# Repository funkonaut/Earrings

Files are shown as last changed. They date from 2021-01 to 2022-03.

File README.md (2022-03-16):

# Earrings
Light up earring art.

[Check out the project website here](https://funkonaut.github.io/project_doc/)

# Design Files
.brd and .sch files availble for EAGLE CAD. 

For each design folder there is also:
- Images of the physical boards
- .step 3D models
- Rendered images of the top and bottom of the board
- A BOM (bill of materials) for the design

# Doc
You can find a prefab checklist and some notes on design rules/process in the .csv and .pdfs. 

There is also a project write up that goes into detail on the design, assembly, and marketing/sales processes that went into this project.

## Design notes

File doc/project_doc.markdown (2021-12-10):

--- 
layout: page
title: "Project Documentation" 
description:
image: /assets/images/doc/Alien_main.jpg
author: Chris Correll
tags: 
--- 

# Emoji Earring Project 

This is the documentation website for a project I undertook in February through April of 2020. I am just now getting around to documenting everything (its December 2021) because I need to wrap up the project so I can feel good about moving on to other designs. What follows is a as comprehensive as I could manage effort to document the whole process from design to manufacturing to marketing. I made a lot of mistake, learned a lot, and over all enjoyed the process immensely (or atleast most parts of the process 😉). Enjoy! 

## Project Background
The project all began when I got my ears pierced...
Chris with pierced ears
I am a hardware nerd at heart and love all things that go blink so I figured a great project would be designing some cool interactive earings. After researching what existed out there and finding that almost everything was either lame or not my style (the folks at [CaliforniaSteam on Tindie](https://www.tindie.com/stores/californiasteam/) are doing cool things but not quite what I wanted) Lame earring I figured it was best to DIY. Additionally, I wanted to know what it would be like to take multiple designs from idea to product line, as well as a personal challenge, see if I could make something that people would actually want to buy. Thusly emoji earrings was born 👂👶.

## Initial Designs

I can't remember how I first came up with the idea to use emojis specifically I think it had something to do with my limited design skills and coming across a trove of open source SVG files for emojis. Perhaps I could just say it came to me out of the ether and leave it at that. After ideating on several different ideas from simple geometric shapes to more complex fractal esque designs I decided to go with a less is more approach and pick something that was universally loved and that I could easily acquire design files for [open source emojis!](https://github.com/hfg-gmuend/openmoji).

After I had figured out the concept for my product line I began thinking about the circuit design. Originally I wanted to do something very circuit heavy with a SAMD microcontroller, a rechargable LiPo battery, and individually addressable LEDs, but I had to remind myself of my limited soldering set up (hot air gun and manual tweezers, see Assembly & Manufacturing section below) and that the focus on the project was creating and manufacturing a product to sell not winning a hacakday hardware design competition... Earring schematic I also decided that I wanted to do one of my favorite emojis the smiley devil so that maybe later on I could also do an angel as well (which I did)!

With a schematic designed I started thinking about parts and board dimensions. I knew I wanted the earrings to be light and small as well I wanted them to be cheap to make, so I scoured digikey and mouser for parts and eventually came up with a high level bill of materials (BOM) that I could base my designs around. I went ahead and ordered some of the parts for prototyping. Devil high level BOM 

With a schematic and a first pass at a BOM it was time to start designing in Eagle. The first challenge was getting the board outline and art into Eagle. Eagle is not made for PCB art but a few smart people have figured out how to finagle it into getting great results. I ended finding [this video by Hackster.io](https://www.youtube.com/watch?v=Wu3JGQQvobg) that made the process super straightforward (well maybe just kind of straight forward). I got my art design from svg to illustrator and then split it up into layers for the pcb art. For a more in depth discussion of what I had to do check out the video above. I also made sure to print my designs on paper to make sure I got a good size for the board.
This is a design I have I split things up into layers and export them all individually
*This is a design I have in illustrator its not the devil design but one I did not end up manufacturing. I split each layer up so I can export and import them into the correct board layer in EAGLE. Its all covered in the wonderful tutorial video linked above (seriously watch that whole video its great).*

Once I got a good size in illustrator I brought my PCB art layers into Eagle starting with the dimension first. Pretty early on I nixed the cr2032 battery design as it was too big for my liking. So I had one BOM item with different foot prints crossed out but was still un decided on a switch, so I ended up designing two different boards. I spent a lot of time thinking about layout for these boards. I would constantly print and then layout my components on printouts of the front and back of the board this really helped make sure I would be able to assemble a bunch of these by hand and that I could minimize the size of the boards and maintain enough clearance for someone to change out the battery. 

Devil final board design
*Dimensions are in millimeters*

## First Prototypes
First Prototype
*First prototype noticed that the face plate is a little smaller than the board outline. Also this was not yet glued hence out of alignment.*

I got the details as perfect as I could manage and I put in two orders to OSH park for some boards. While I was waiting for the OSH park orders a friend of mine who had access to a cnc mill offered to mill out one of my designs for beer (thanks Zoltan!) so I ended up getting the chunkier switch design in before the boards. I soldered it up and it all worked! I then proceeded to test different resistor values and leds to find the best brightness for lowest current consumption (V=IR thanks math!). I ended settling on 2.2k, also had a lot of those around in 0603 packages. When I had the boards soldered up I had the idea of adding an acrylic faceplate to it to add some heft and more interest to the design as it was still very light. Since I already had the vector file of the outline from desiging the outline cutting it out on a friends laser cutter was pretty straight forward. Unfortunately I didn't realize that the milled circuit board dimensions were slightly larger than the design file so the first pass had the board peaking out from underneath. I went ahead and dialted the vector file slightly just in case as I was fine with a little bit of acrylic face plate over hang but not with any board showing underneath the acrylic outline.
Clear frosted acrylic faceplate
Originally I was gonna go with a clear frosted acrylic as I thought it might diffuse some of the light interestingly but I did not really do much as the angle that the light was being emitted was not all that wide so it just shot throug the eye holes in the acrylic. So I decided on going with a pink sheet of acrylic. 

Alien board design
*Dimensions are in millimeters*

While I was waiting on boards to come in I also started designing my second piece an alien emoji. This design went a little quicker since I had gotten the PCB art Eagle design process down better. Once I was happy with the design I went ahead and ordered some boards from PCB Way. I love OSH park but I had to do the alien in green also I wanted to see what a thinner board felt like. With two different designs under way I decided to get organized a created some project organization bags.

Project Organization bags post project so they are full
*Project Organization bags post project so they are full*

Also being PCB Way where 5 boards and 50 boards have a cost differential of about $20 I went ahead and bought a bunch (like 60), a mistake I would later come to regret... 

Tiny switch
*So smol*

Around 2 weeks later I got the devil boards back from OSH park. I soldered up both a chunky switch and a small switch design they both worked great, but the small switch was very cumbersome to turn off and on so I ditched it. I had my BOM finalized so I but in an order to OSH park for 48 boards and then bought all my parts plus around 5% extra from digikey. While the boards from PCB Way's cost scaled well, parts and OSH park boards did not so I ended up spending a bunch of money, but no big deal I would recoup that cost by selling them, little did I know...

Laser cut green faceplate
Once I got the aliens back I started experimenting with laser cut face plates for them and found that I liked a transulent green finish instead of a solid green finish. I liked being able to see the pcb board underneath. This would lead to some minor issues later during assembly and manufacturing. 

## Assembly & Manufacturing

Ready to Assemble

Now that I had all the boards it was time to start manufacturing and assembly. This is the part of the process that I really started to loathe. Assembling over 100 circuit boards with a hot air gun and soldering iron is hell, I really feel for those factory workers. My set up could have definietly been better and eventually I did get a small reflow over from a friend (thanks again Zolatan!) and cut out some solder stencil out of kapton, but I defintely learned that while assemblying prototypes is fun, assemblying for manufacturing is work. I ended up making it through about 1/2 of the boards before throwing in the towel.
So many boards
 
All in all it was sometimes nice to get in a flow for a couple of hours and knock out 8 or 9 boards but I know now why a pick and place machine exits. I didn't have a nice microscope to aide in hand placement and I definitely got eye strain over a stretch of time. I think in the future getting a set up similar to [this guy](https://www.youtube.com/watch?v=HmPYuOIMDJs) would be useful. I still have around 50 or so unassembled baords and maybe one day I will get to making them but I am happy with having made as many earring pairs as I did.

Laser cut sheet of alien faceplates
In addition to the PCB assembly process I also had to figure out an assembly process for the acrylic face plates. Laser cutting the acrylic ended up being a little trickier then I thought. I wasn't working with the best machine out their and it did take a couple of passes to get through the acrylic. As well the laser strength would sometimes leave marks on the acrylic. For the solid pink devil face plates this was not as much as of an issue. I could just flip them over and use the unmarred side but I had to trash some of the alien face plates good thing I ended up cutting like 30 extra since I had the acrylic and it was relatively unexpensive.

Laser cut devil faceplates

I also found that putting a sheet of black paper underneath the acrylic helped with some marks. In the future though I think the best bet is to tune the machine a little bit better with scraps of the material.

With all of the faceplates I had to figure out a way to glue them on to my assembled board. For the solid faceplates it was easy I would just use CA (super) glue and then clothes pin the faceplates to clamp it down in place as it dried. For the translucent acrylic though I ran into some issues with CA glue artifacts.

Glue artifacts

Apparently CA glue has a tendency to fog plastic when it dries. I read on [the internet](https://www.reddit.com/r/modelmakers/comments/2ru0co/stupid_question_when_working_with_super_glue_how/) that this might be due to lack of air circulation so I tried pointing the heat gun at the pieces as they dried this kind of helped but still was having so issues. So I ended up going with a CA accelerator (no more clothes pins!) and a more conservative application of the super glue. This helped but still I would get some pieces that still fogged a noticable amount. I think in the future going with a bi-component cement glue or polystyrene glue would be a better bet I just had a lot of CA glue and I was not able to find the aforementioned at the local hardware store. Also I grew to kind of like the look of the fog on the face plates. That said this is one area I would definitely like to improve on if I finish the rest of the boards ever.

Not enough glue
*Conservatively apply super glue but enough that it bonds!*

Gluing process finalized
*Final gluing process*

Hot air gun reflowing
Eventually I figured out a nice assebly process, it ended up being as follows:
- Gather components and get ready to assemble (see photo at beginning of section)
- Apply solder paste using stencil or by hand (I found that going by hand was actually faster)
- Use tweezers to place components on bottom of boards
- Reflow components
- Fix any components that might have not seated properly during the reflow stage
- Test to make sure connections are sound
- Hand solder or use the hot air gun to reflow the leds on the top part of the board 
- Test that the board works with a test battery 
- Once the board has been confirmed to work file down the edges of the board where they were depanelized using side cutters and sand paper 
- Add marker to the exposed fr4 so it matches the solder mask color
- Apply super glue to the front of the board and accelerator to the faceplate and bind them work quickly you will only have like 1-2 seconds before it bonds
- Attach earring hardware
- Enjoy!

Final Products
*These but like times 10*

## Standardizing the Design process
Design check list

Once I had gotten through the first batch of manufacturing (well half of the first batch) I was hungry to get back to designing more earrings as that was what I really enjoyed. So I took what I learnt from designing and building the first batch of devils and aliens and formalized a design checklist to help guide my design process for the board files. Things ended up going a lot faster once I had the checklist and I added to it as I made more designs!

## More Designs!
I ended up designing and manufacturing (albeit in much smaller quantities) 5 other designs, and designed 3 that I did not end up getting made. I didn't have access to a laser cutter at the time so they did not have any faceplates, but I was happy with how they turned out. 

Skull pcbs
Continuing with emoji theme I made a couple of skulls in multiple colors as well as an angel to compliment by devil work. 

Designs not yet made
I also made a couple of other designs that I did not end up making.

Check out the gallery for more pictures and [the project github](https://github.com/funkonaut/Earrings) for more pictures and design files!

Cross with red LED
The cross didn't really fit the theme but I was feeling gothic, and wanted to see how far I could push OSH parks fabrication. It turns out really far! This also gave me some great ideas for future earring projects. I cheated on the circuit design and found some integrated LEDs and IC that had the LED color cycle... 

## Marketing
Bedroom photography studio set up

It turns out you can get pretty solid shots with a roll of paper, some lamps and a mid level dslr (oh and photoshop...). 

I learned a lot preparing marketing shots and content, namely that its okay. I enjoy it way more then assembly and manufacturing but not as much as design. I also learned that you got to check you settings half way through the shoot I realized I was not shooting in raw so some of my images vary in quality. Most importantly I learned that you got to take more photos than you think necessary because it is hard to go back and get consistent lighting especially in a make shift studio. Oh and having a shot list help guide your photo session is very helpful!

## Sales and Logistics
Etsy logo
With all my marketing content prepared I opened my Etsy shop. I am pretty sure all of my purchases were friends and family, though I think I had one or two strangers grab a pair which was pretty cool.

Market set up
*I also sold at a friends out door market. I remixed some of the earrings into beaded necklaces and bracelets which was fun but I think I like them better as earrings.*

Packaging the earrings and sending them out was not too difficult. I just put them in anti static bags and had Etsy generate the shipping labels. Eventually I made the decision to close down the shop as I did not really care to promote the project much more then just to friends and family after selling around 15 pairs of earrings and giving away around 5 more. I also did not end up posting on [Tindie](https://www.tindie.com/), an option I would probably like to explore more in the future.

Devil marketing shot
*Goodbye Etsy for now...*

## BOMbing it
Devil final BOM and cost break down
*Per earring cost for the devil design*

Each earring ended up costing around $4 and around 30 minutes to assemble (I am slow :/) the electronics, faceplate, and earring hardware. At $8 per pair and around an hour of labor I decided to charge $24.99 for each earring pair. 

Expenses list
I ended up spending almost $900 for the project and made back $400. So I lost $500 when it was all said and done. I still have a fair amount of unassembled merch and if I were to assemble and sell all of those I would gross a couple of hundred of dollars, but this was never about making money, it was about learning!

## Back to the Drawing Board...
Perhaps the most valuable lesson I found after the whole ordeal of trying to sell and market things, is that I really enjoy the design and prototyping process much more than the whole selling, assembling and manufacturing the designs. I guess I could always have a PCB assembly house manufacture things but I am not sure if I feel great about that especially after experiencing how rough that work is first hand (I get they have pick and place machines but still really thankful for those manufacturing employees). Also a PCBA process costs at the cheapest like $5 extra per board so would bring the cost of the earrings closer to $20 which is a pretty alright profit margin at scale but I am not super interested in making and marketing these things at scale.

### Here is a list of my main project take aways:
- Probably dont tie large copper pours meant for aesthetics to signals to prevent accidentally shorting
- Probably coat dangling metal or large copper pours so it doesnt short things
- Defintely add short protection for that coin cell
- Go small when purchasing, just because you can buy large quantities does not mean you should!
- Gotta give myself easier tolerances for assembling these things I have bigger resistors probs should haev used them
- Documentation isnt all that bad do it as you go don't do it all at the end...
- Make sure Eagle has 3D packages attached to the parts you are designing with so you can get 3D models really easily
- Add more silkscreen assembly marks to help when manufacturing, you can always hide the marks under parts if you do not want them to show
- Add to github as you go, version control is your best friend...

Now that I can say I have wrapped up this project stay tuned for more cool earring projects with improved circuitry and even more aesthetic designs!

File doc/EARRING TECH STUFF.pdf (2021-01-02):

EARRING TECH STUFF

QUESTIONS
Clearance for resistors/battery holder?
How to remove battery in design?
Standardize width and height is 23mm to big awkward? Find good proportion Should reposition batt/ cover for easier access? Or will square hoop solve problem?

DESIGN DECISIONS/NOTES
In AI keep assets layer for working with paths before compounding them Gold color fec248
Copper color#b87333
FR4 color D8D850
Build layer file in illustrator
Make sure silk screen is clean
SHRINK TSTOP by like .5mm to keep from having copper outline
Make sure switch is the same on (to the right like devil change alien)
Copper clearance to edge
Change ALIEN hole to 1.5mm from 2mm on laser cut file after cutting front plates All LEDs 0805
Jewelry holes 2mm hole or 1.5mm drill/ 2mm annular and via to ground ~.25-.5mm clearance from hole to dimension
.35mm traces unless not able for routing
.254 vias for OSH Park .3 vias for PCBWAY
Vias covered with solder mask on back
All components except lights on back Full solder mask on back
Exposed copper front
Gold plating
White silk screen
2-6 LEDS depending on design .8mm board thickness

LASER CUTTING 30w epilogue
Put black paper under to stop reflections CUT 8s 100p 5000hz

DIMENSIONS/MECH TECH SPECS Laugh

25mm width 23mm height

Heart eyes

23mm width 23mm height
Angel

23mm width 23.5mm height
Devil

25mm width 23.6mm height 3.75g (acrylic and hoops) 2.5g (hoops) Alien

20.5mm width 24.5mm 2.35g (hoops)
Cry

22.6mm width 22.6mm height (redo?) 23mm width 23 height

ECO
-On all gold faces maybe do not make ground just make it a NC so no possibility of short to ground***
-On angel make it so fr4 is exposed on back
-On earrings w/o face plates order them 1.6mm thickness better feel
-Make all vias as small as OSH Park limit
-Be careful with exposed gold plated surfaces its really hard to assemble that way -make copper pour and pad clearance excessive
-if possible include silkscreen or solder mask around pads

-Skull: get rid of gold teeth version
-Skull: move down resistor as far as possible from the battery holder -Texas: more clearance around copper pour?
-Texas: make face plate no connect if not already

ILLUSTRATOR NOTES
object> Expand appearance > expand to turn path into two paths from one path stroke

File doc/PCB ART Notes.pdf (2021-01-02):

## PCB ART Notes

Links
https://www.youtube.com/watch?v=Wu3JGQQvobghttps://www.youtube.com/watch?v=EI2CLwQi6N0

Notes:
-Gerbers can’t do donuts slice it all up
-Don’t trust the silk screen it will not be accurate on printing better to use solder mask or copper don’t know where pcb manufacturer will land it so make it able to drift around
-specify layers in illustrator (ie outline copper solder mask silk)
-Make solder mask layer slightly opaque so you can see copper underneath -Add lots anchor points
-Simplify to make all straight lines 2 degree should work straight lines box checked
-If super complex break it into a grid (15m15s) select empty ones and delete

Steps:
Make file all straight lines
-add anchor points can’t do it too much
-simplify 2 degree threshold or 1 for more curves

Break things into smaller pieces
-rectangular grid tool (in line segment tool)
-25 by 25 div should work
-dont do this for top copper and board outline (doesn’t work for that) -divide paths with grid lines
-select empty square
-select> same > fill and stroke
-use X-ray mode (ctrl y) to make sure it looks good
-save it

Separate those layers
-one by one delete from master file (saved in last step) to get the different layers -save them as .ai files illustrator 10 works best with Inkscape
-default import into Inkscape
-assign fill
-save as .svg***

Get the EAGLE stuff

-Run SVG to Eagle script
-import into text editor
-save as .scr file

Run Dimensions .scr
-change from filled poly in eagle to unfilled right click outline convert to wires replace

Tips:
-Add art to design last; polygons make it hard to work with sometimes

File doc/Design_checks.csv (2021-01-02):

 | Design Component | Check
FALSE | Switch | -clearance from edge
FALSE | Switch | -clearance from battery gnd solder joint and battery and won’t touch if battery pressed too far in
FALSE | Switch | -turn on/ off position consistent
FALSE | Switch | -routed correctly
FALSE | LED | -placement correct
FALSE | LED | -vias hidden in pads if possible
FALSE | LED | -pakage size correct 0805
FALSE | LED | -has a resistor
FALSE | LED | -correctly connected
FALSE | Battery | -clearance from edge
FALSE | Battery | -battery ground clearance from pads and components
FALSE | Battery | -battery VCC clearance from components and pads
FALSE | Battery | -direction of battery mount makes sense battery is insertable
FALSE | Earring Mounting Hole | -fits jumper ring (1.7mm)
FALSE | Earring Mounting Hole | -clearance from edge
FALSE | Earring Mounting Hole | -if its via is it gonna short anything? Esp with conductive jumper
FALSE | Planes | -unbroken ground plane
FALSE | Planes | -all connections being made for all planes
FALSE | Vias | -masked over
FALSE | Vias | -.254mm min OSH .3mm PCBWAY
FALSE | Routing | -playful (curvy and aesthetically pleasing)
FALSE | Routing | -as hidden as possible by solder mask and screen
FALSE | Routing | -clearance from objects use normal drc
FALSE | Routing | -signals traces check mentally
FALSE | Solder mask Top/ bottom | -tstop is correct
FALSE | Solder mask Top/ bottom | -t restrict does not leave any weird gaps to show fr4 through
FALSE | Solder mask Top/ bottom | -bstop is correct
FALSE | Solder mask Top/ bottom | -b restrict does not leave any weird gaps to show fr4 through
FALSE | Order Details | make sure board is correct thickness
FALSE | Order Details | make sure board is correct color
FALSE | Order Details | Gold plating

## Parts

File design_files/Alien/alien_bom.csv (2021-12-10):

Part | Value | Device | Package | Description | HEIGHT | MANUFACTURER_NAME | MANUFACTURER_PART_NUMBER | MOUSER_PART_NUMBER | MOUSER_PRICE-STOCK | POPULARITY | SPICEPREFIX
LED1 |  | LEDCHIP-LED0805 | CHIP-LED0805 | LED |  |  |  |  |  | 68
LED2 |  | LEDCHIP-LED0805 | CHIP-LED0805 | LED |  |  |  |  |  | 68
R2 | 2.2k | R-US_R0603 | R0603 | RESISTOR, American symbol |  |  |  |  |  | 77 | R
R3 | 2.2k | R-US_R0603 | R0603 | RESISTOR, American symbol |  |  |  |  |  | 77 | R
U$1 | Dpdt switch | CL-SB-22A-02T-SLIDE-SWITCH-TUCKED-PADS | CL-SB-22A-11T side setting | (names in device are wrong)
VBAT | BAT-HLD-012-SMT | BAT-HLD-012-SMT | BATHLD012SMT | Coin Cell Battery Holders Bat Hld CR1216/1225 Surface Mount | 3mm | Linx Technologies | BAT-HLD-012-SMT | 712-BAT-HLD-012-SMT | https://www.mouser.com/Search/Refine.aspx?Keyword=712-BAT-HLD-012-SMT

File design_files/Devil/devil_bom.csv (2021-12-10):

Part | Value | Device | Package | Description | HEIGHT | MANUFACTURER_NAME | MANUFACTURER_PART_NUMBER | MOUSER_PART_NUMBER | MOUSER_PRICE-STOCK | POPULARITY | SPICEPREFIX
LED1 |  | LEDCHIP-LED0603 | CHIP-LED0603 | LED |  |  |  |  |  | 26
LED2 |  | LEDCHIP-LED0603 | CHIP-LED0603 | LED |  |  |  |  |  | 26
R2 |  | R-US_R0603 | R0603 | RESISTOR, American symbol |  |  |  |  |  | 77 | R
R3 |  | R-US_R0603 | R0603 | RESISTOR, American symbol |  |  |  |  |  | 77 | R
U$1 | CL-SB-22A-02T-SLIDE-SWITCH-TUCKED-PADS | CL-SB-22A-02T-SLIDE-SWITCH-TUCKED-PADS | CL-SB-22A-11T side setting | (names in device are wrong)
VBAT | BAT-HLD-012-SMT | BAT-HLD-012-SMT | BATHLD012SMT | Coin Cell Battery Holders Bat Hld CR1216/1225 Surface Mount | 3mm | Linx Technologies | BAT-HLD-012-SMT | 712-BAT-HLD-012-SMT | https://www.mouser.com/Search/Refine.aspx?Keyword=712-BAT-HLD-012-SMT

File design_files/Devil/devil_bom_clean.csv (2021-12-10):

Part | Value | Device | Package | Description | Cost | URL
LED1 | Pink | LEDCHIP-LED0603 | CHIP-LED0603 | LED | 0.03 | https://www.digikey.com/en/products/detail/everlight-electronics-co-ltd/EAST1608GA5/5142399
LED2 | Pink | LEDCHIP-LED0603 | CHIP-LED0603 | LED | 0.03 | https://www.digikey.com/en/products/detail/everlight-electronics-co-ltd/EAST1608GA5/5142399
R2 | 2.2k | R-US_R0603 | R0603 | RESISTOR, American symbol | 0.01 | https://www.digikey.com/en/products/detail/stackpole-electronics-inc/RMCF0603JT2K20/1758069
R3 | 2.2k | R-US_R0603 | R0603 | RESISTOR, American symbol | 0.01 | https://www.digikey.com/en/products/detail/stackpole-electronics-inc/RMCF0603JT2K20/1758069
U$1 | SPDT | CL-SB-22A-11T side setting | CL-SB-22A-11T side setting | SPDT side switch smd (listed as CL-SB-22A-12T on digikey but as device on manufacturers web site?) | 1.26 | https://www.digikey.com/en/products/detail/nidec-copal-electronics/CL-SB-22A-12T/3507830
VBAT | cr1216 holder | BAT-HLD-012-SMT | BATHLD012SMT | Coin Cell Battery Holders Bat Hld CR1216/1225 Surface Mount | 0.29 | https://www.digikey.com/en/products/detail/linx-technologies-inc/BAT-HLD-012-SMT/3044013
BAT | CR1216 | CR1216 | CR1216 | LiPo coin cell battery 12.5mm x 1.6mm | 0.33 | https://www.digikey.com/en/products/detail/tianqiu/CR1216/14565062
Board | Standard f4 from OSH park | n/a | n/a | 3 for $5/ sq. inch +shipping cost | 1.75 | https://www.oshpark.com
Earring HW | Earring jumper hoops and hooks | n/a | n/a | Estimated cost overstock | 0.03
Acrylic | 1/8” cast acrylic in pink | n/a | n/a | Sheet costs $9.99 for sq foot | 0.2
 |  |  |  | TOTAL COST | 3.94

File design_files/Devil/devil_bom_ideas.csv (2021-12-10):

Part | Value | Package | Notes | Cost | URL
LED1 | Pink | 0603 | LED | 0.03 | https://www.digikey.com/en/products/detail/everlight-electronics-co-ltd/EAST1608GA5/5142399
LED2 | Red | 0603 | LED | 0.02 | https://www.digikey.com/en/products/detail/everlight-electronics-co-ltd/EAST1608GA5/5142399
LED3 | Green | 0603 | LED | 0.03 | https://www.digikey.com/en/products/detail/everlight-electronics-co-ltd/EAST1608GA5/5142399
LED4 | Pink | 0805 | LED | 0.03 | https://www.digikey.com/en/products/detail/everlight-electronics-co-ltd/EAST1608GA5/5142399
LED5 | Red | 0805 | LED | 0.02 | https://www.digikey.com/en/products/detail/everlight-electronics-co-ltd/EAST1608GA5/5142399
LED6 | Green | 0805 | LED | 0.03 | https://www.digikey.com/en/products/detail/everlight-electronics-co-ltd/EAST1608GA5/5142399
Resistors | 1k-10k | R0603 | Cheap 5% tolerance I have so many of these let just use what I got and check the brightness | 0
Switch1 | SPDT | CL-SB-22A-12T | SPDT side switch smd | 1.26 | https://www.digikey.com/en/products/detail/nidec-copal-electronics/CL-SB-22A-12T/3507830
Switch2 | SPDT | PCM12-SMTR | SPDT side switch smd | 0.90 | https://www.mouser.com/ProductDetail/CK-Switches/PCM12SMTR?qs=mfFuH…
VBAT1 | cr1216 holder | BATHLD012SMT | Coin Cell Battery Holders Bat Hld CR1216/1225 Surface Mount | 0.29 | https://www.digikey.com/en/products/detail/linx-technologies-inc/BAT-HLD-012-SMT/3044013
VBAT2 | Cr2032 holder | BAT-HLD-001 | Coin Cell Battery Holders Bat Hld CR2032 Surface Mount | 0.32 | https://www.mouser.com/ProductDetail/Linx-Technologies/BAT-HLD-001
BAT1 | 3.3V | CR1216 | LiPo coin cell battery 12.5mm x 1.6mm | 0.33 | https://www.digikey.com/en/products/detail/tianqiu/CR1216/14565062
BAT2 | 3.3V | CR2032 | Have some of these laying around | 0

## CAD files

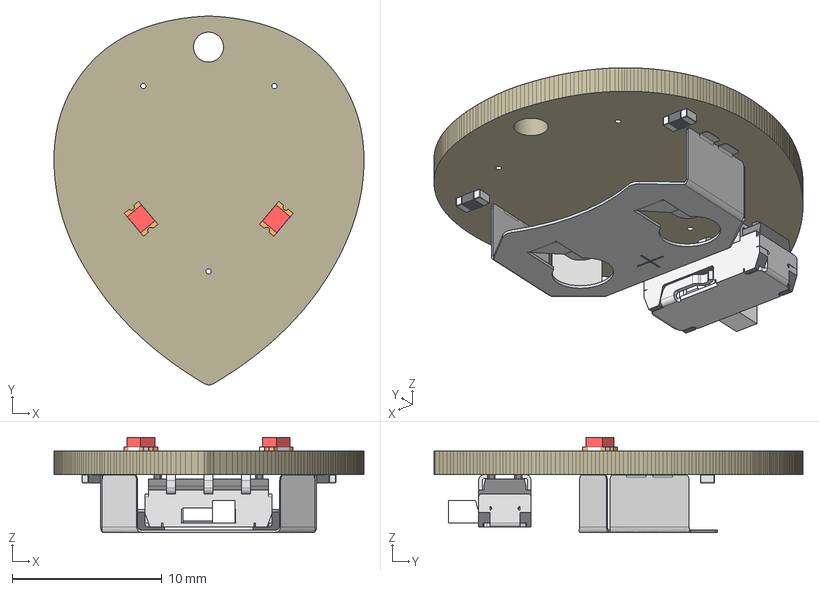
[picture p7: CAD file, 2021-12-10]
design_files/Alien/alien.step
20.7 x 24.6 x 6.34 mm
Board
CHIP-LED0805 x 2
2.2k x 2
BAT-HLD-012-SMT
_22A-11_c
_2Side setting_s

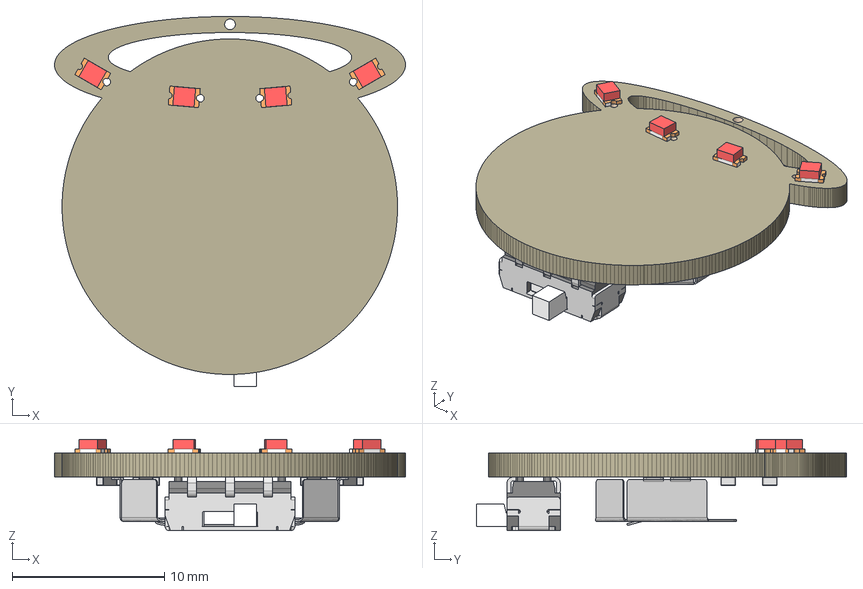
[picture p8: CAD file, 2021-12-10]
design_files/Angel/angel.step
23.0 x 24.3 x 5.97 mm
Board
CHIP-LED0805 x 4
R0603 x 4
_22A-11_c
_2Side setting_s
BAT-HLD-012-SMT

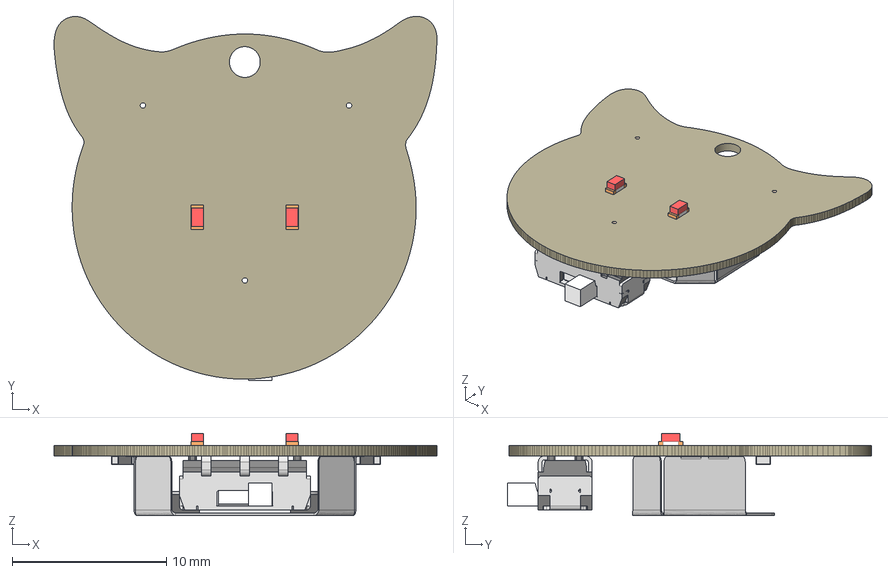
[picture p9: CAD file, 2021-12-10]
design_files/Devil/devil.step
24.9 x 23.6 x 5.34 mm
Board
CHIP-LED0603 x 2
R0603 x 2
BAT-HLD-012-SMT
_22A-11_c
_2Side setting_s

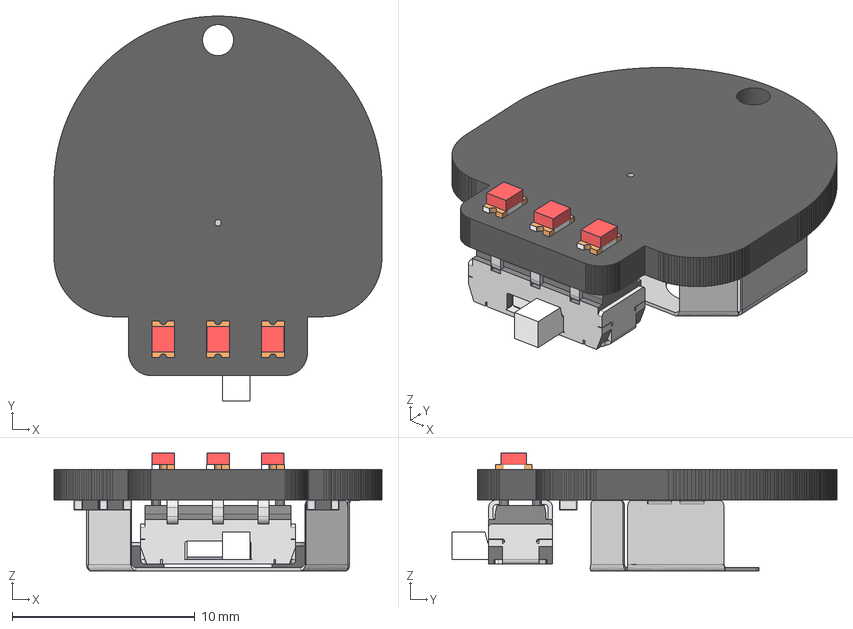
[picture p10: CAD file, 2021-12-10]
design_files/Skull/skull_white.step
18.0 x 21.1 x 6.44 mm
Board
CHIP-LED0805 x 3
R0603 x 3
BAT-HLD-012-SMT
_22A-11_c
_2Side setting_s

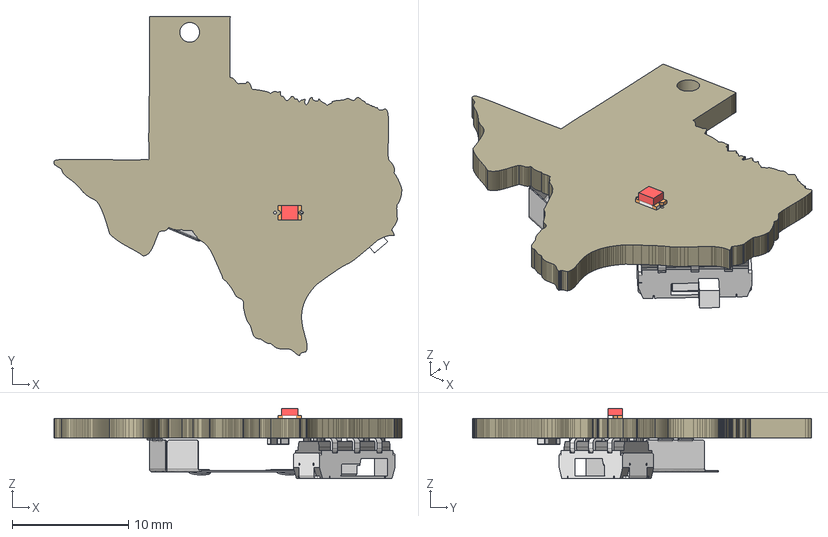
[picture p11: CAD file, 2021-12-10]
design_files/Texas/Texas.step
30.0 x 29.3 x 6.07 mm
Board
CHIP-LED0805
R0603
_22A-11_c
_2Side setting_s
BAT-HLD-012-SMT

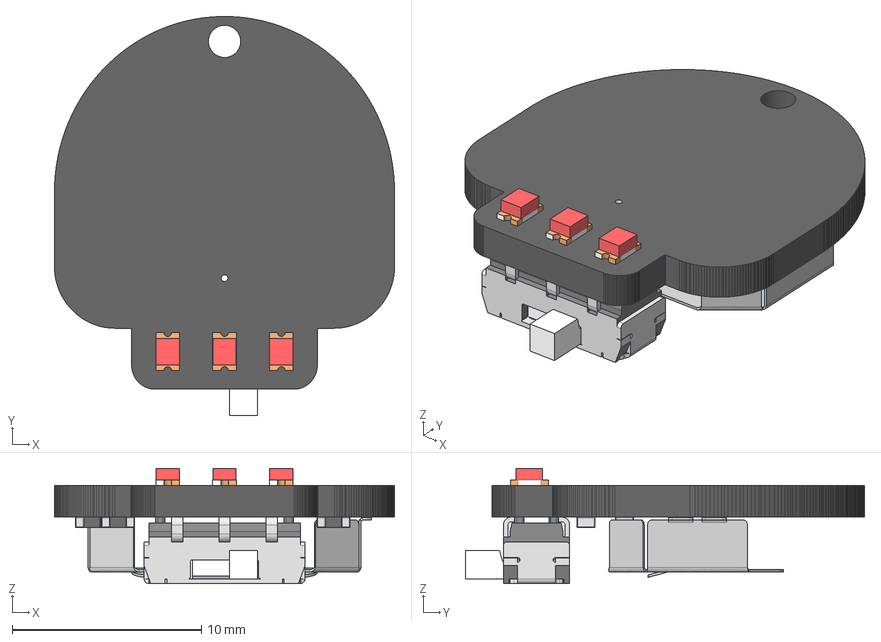
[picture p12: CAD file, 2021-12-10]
design_files/Skull/skull_black.step
18.0 x 21.1 x 6.07 mm
Board
CHIP-LED0805 x 3
R0603 x 3
BAT-HLD-012-SMT
_22A-11_c
_2Side setting_s

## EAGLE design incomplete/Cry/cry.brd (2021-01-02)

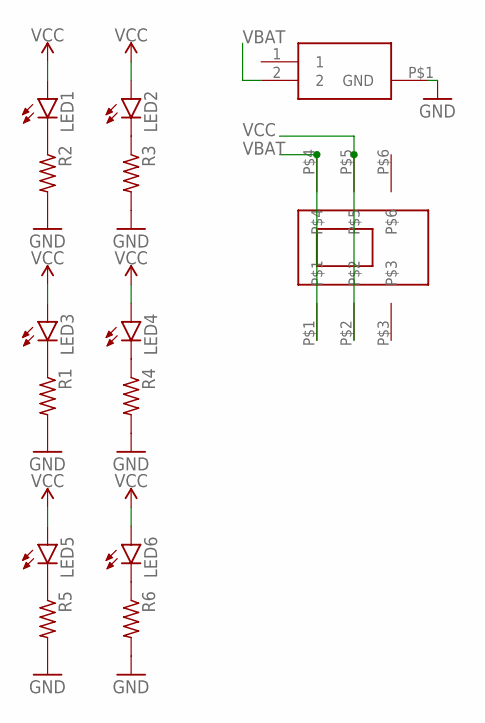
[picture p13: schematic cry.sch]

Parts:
LED1, LED2, LED3, LED4, LED5, LED6: LEDCHIP-LED0805; CHIP-LED0805
R1, R2, R3, R4, R5, R6: R-US_R0603; R0603
U$1: CL-SB-22A-02T-SLIDE-SWITCH-TUCKED-PADS; CL-SB-22A-02T-DPDT-COMPACT-SWITCH
VBAT: BAT-HLD-012-SMT; BATHLD012SMT

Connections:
GND: R1.2, R2.2, R3.2, R4.2, R5.2, R6.2, VBAT.P$1 (GND)
unnamed: LED1.C, R2.1
unnamed: LED3.C, R1.1
unnamed: LED2.C, R3.1
unnamed: LED4.C, R4.1
unnamed: LED5.C, R5.1
unnamed: LED6.C, R6.1
VBAT: U$1.P$1, U$1.P$4, VBAT.2
VCC: LED1.A, LED2.A, LED3.A, LED4.A, LED5.A, LED6.A, U$1.P$2, U$1.P$5

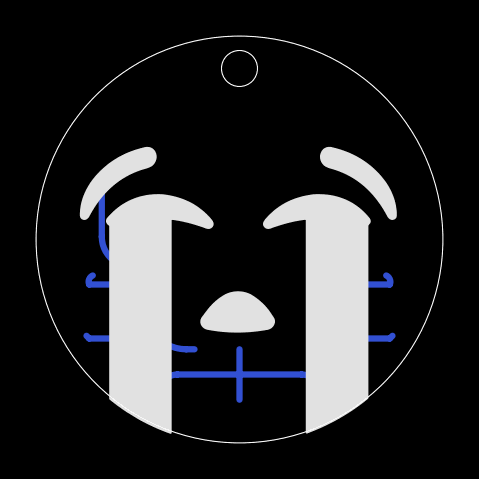
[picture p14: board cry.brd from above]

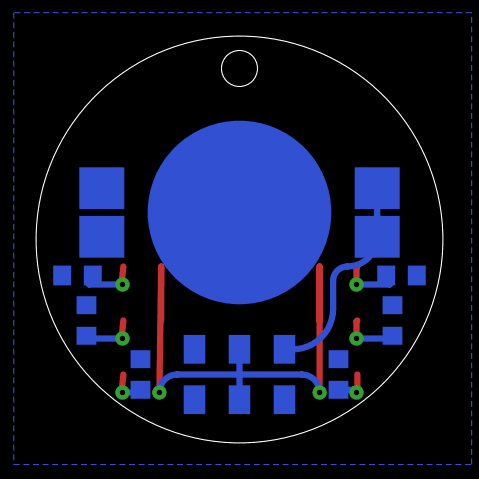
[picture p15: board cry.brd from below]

Board: 2 copper layers, 22.6 x 22.6 mm, 14 parts (8 on the bottom side), 9 nets.

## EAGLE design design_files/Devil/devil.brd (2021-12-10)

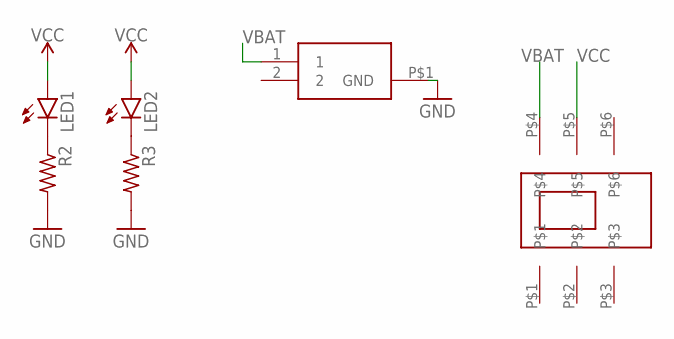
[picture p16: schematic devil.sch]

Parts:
LED1, LED2: LEDCHIP-LED0603; CHIP-LED0603
R2, R3: R-US_R0603; R0603
U$1: CL-SB-22A-02T-SLIDE-SWITCH-TUCKED-PADS; CL-SB-22A-02T-DPDT-COMPACT-SWITCH
VBAT: BAT-HLD-012-SMT; BATHLD012SMT

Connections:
GND: R2.2, R3.2, VBAT.P$1 (GND)
unnamed: LED1.C, R2.1
unnamed: LED2.C, R3.1
VBAT: U$1.P$4, VBAT.1
VCC: LED1.A, LED2.A, U$1.P$5

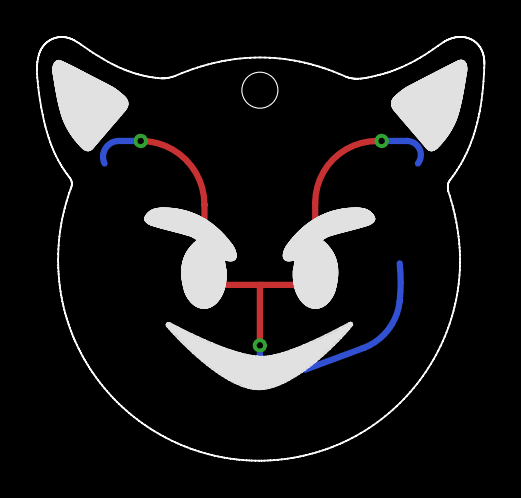
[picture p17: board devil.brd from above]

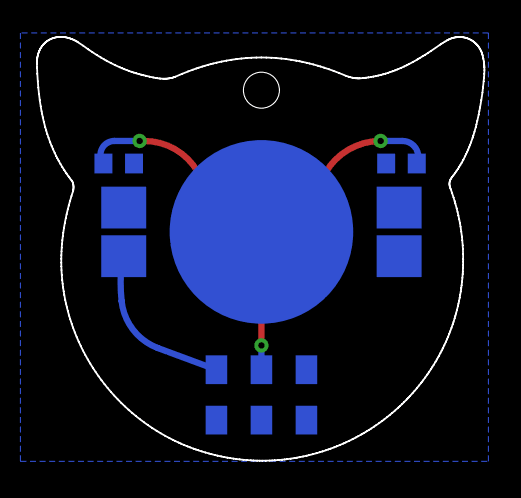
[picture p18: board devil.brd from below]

Board: 2 copper layers, 24.9 x 23.5 mm, 6 parts (4 on the bottom side), 5 nets.

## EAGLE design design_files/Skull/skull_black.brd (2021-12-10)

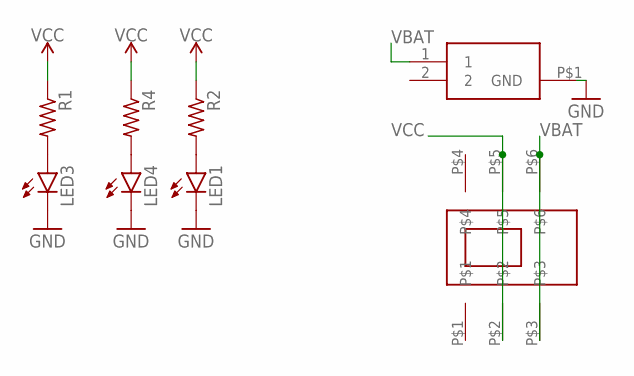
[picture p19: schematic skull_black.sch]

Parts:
LED1, LED3, LED4: LEDCHIP-LED0805; CHIP-LED0805
R1, R2, R4: R-US_R0603; R0603
U$1: CL-SB-22A-02T-SLIDE-SWITCH-TUCKED-PADS; CL-SB-22A-02T-DPDT-COMPACT-SWITCH
VBAT: BAT-HLD-012-SMT; BATHLD012SMT

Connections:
GND: LED1.C, LED3.C, LED4.C, VBAT.P$1 (GND)
unnamed: LED1.A, R2.2
unnamed: LED3.A, R1.2
unnamed: LED4.A, R4.2
VBAT: U$1.P$3, U$1.P$6, VBAT.1
VCC: R1.1, R2.1, R4.1, U$1.P$2, U$1.P$5

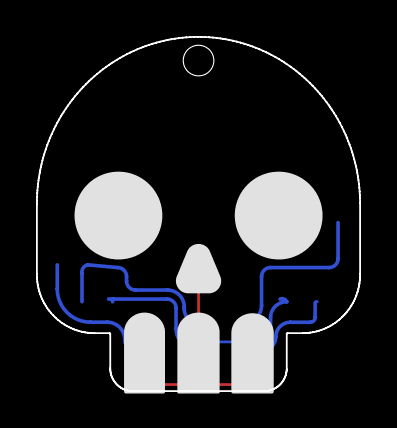
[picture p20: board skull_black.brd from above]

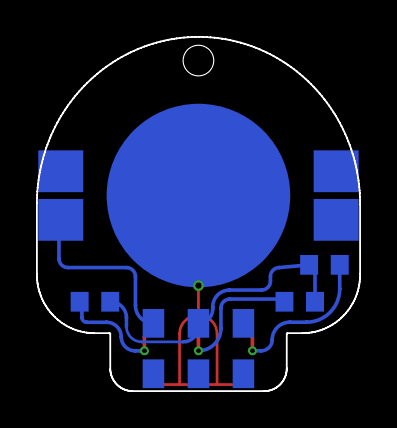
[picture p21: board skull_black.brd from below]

Board: 2 copper layers, 18.0 x 19.7 mm, 8 parts (5 on the bottom side), 6 nets.

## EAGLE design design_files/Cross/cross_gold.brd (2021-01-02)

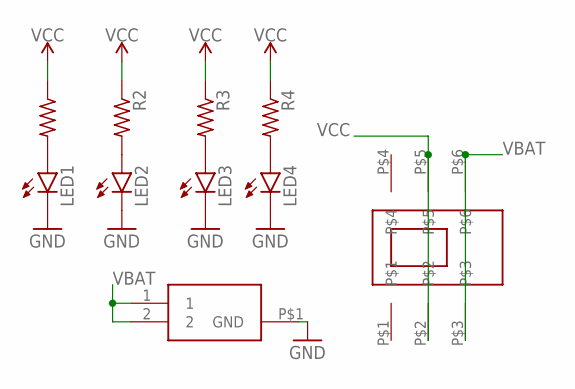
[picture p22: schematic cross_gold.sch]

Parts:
LED1, LED2, LED3, LED4: LEDCHIP-LED0805; CHIP-LED0805
R1, R2, R3, R4: R-US_R0603; R0603
U$1: CL-SB-22A-02T-SLIDE-SWITCH-TUCKED-PADS; CL-SB-22A-02T-DPDT-COMPACT-SWITCH
VBAT: BAT-HLD-012-SMT; BATHLD012SMT

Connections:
GND: LED1.C, LED2.C, LED3.C, LED4.C, VBAT.P$1 (GND)
unnamed: LED1.A, R1.2
unnamed: LED2.A, R2.2
unnamed: LED3.A, R3.2
unnamed: LED4.A, R4.2
VBAT: U$1.P$3, U$1.P$6, VBAT.1, VBAT.2
VCC: R1.1, R2.1, R3.1, R4.1, U$1.P$2, U$1.P$5

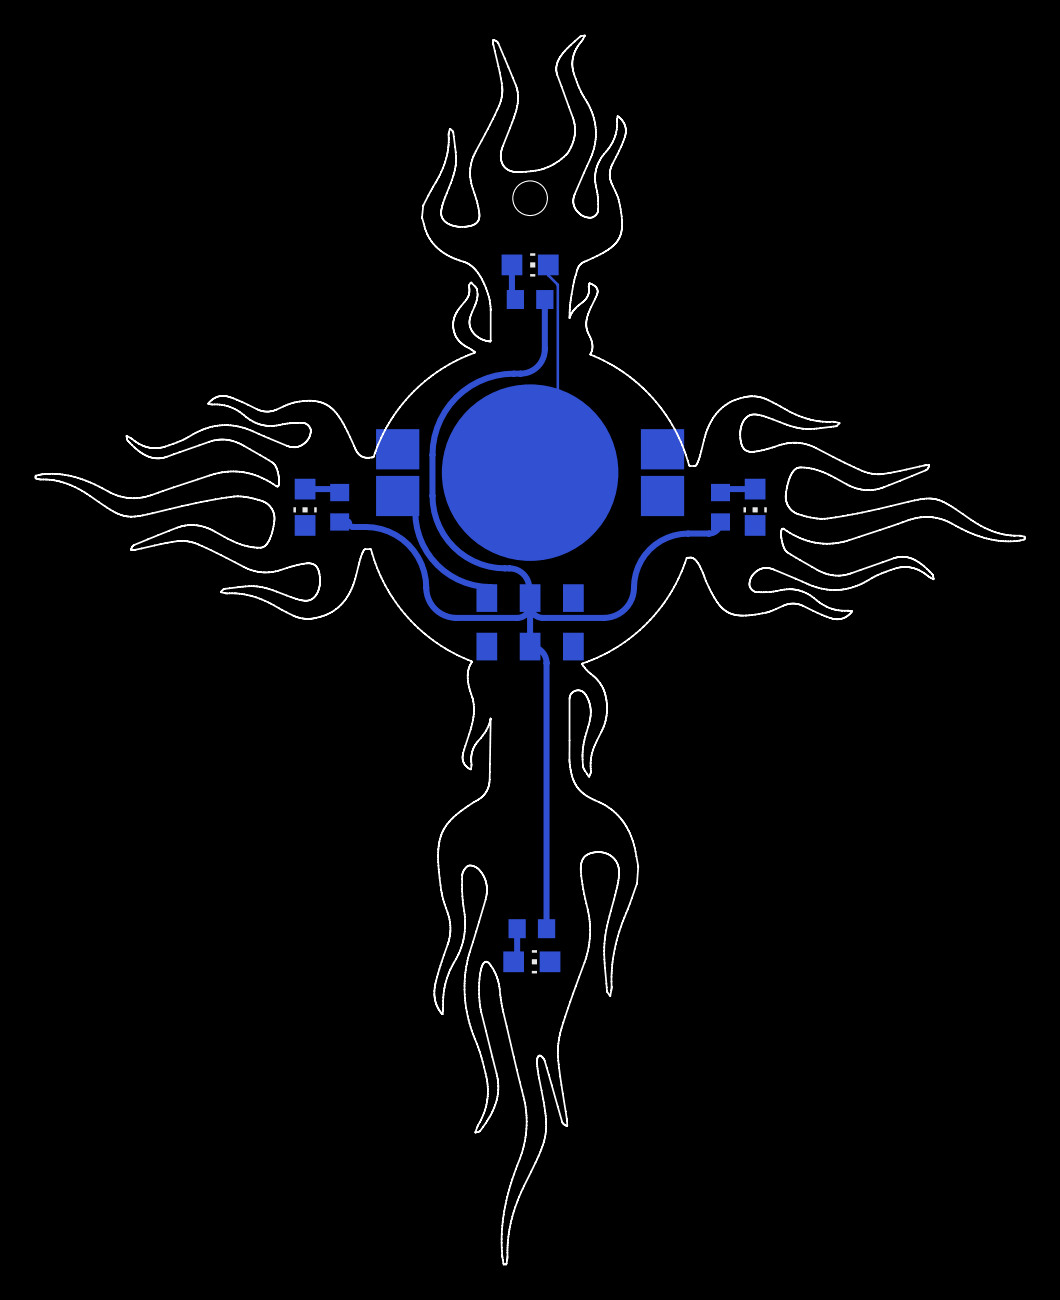
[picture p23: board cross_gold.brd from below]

Board: 2 copper layers, 57.1 x 71.0 mm, 10 parts (10 on the bottom side), 7 nets.

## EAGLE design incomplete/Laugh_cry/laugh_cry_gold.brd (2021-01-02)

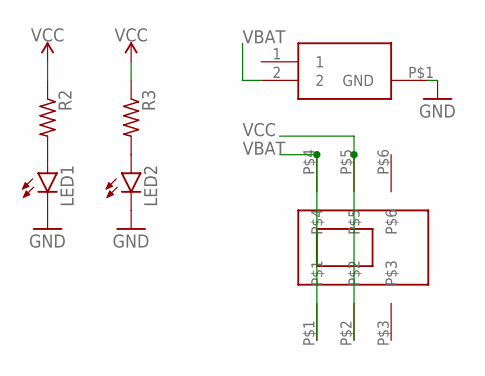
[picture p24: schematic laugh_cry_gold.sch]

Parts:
LED1, LED2: LEDCHIP-LED0805; CHIP-LED0805
R2, R3: R-US_R0603; R0603
U$1: CL-SB-22A-02T-SLIDE-SWITCH-TUCKED-PADS; CL-SB-22A-02T-DPDT-COMPACT-SWITCH
VBAT: BAT-HLD-012-SMT; BATHLD012SMT

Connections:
GND: LED1.C, LED2.C, VBAT.P$1 (GND)
unnamed: LED1.A, R2.2
unnamed: LED2.A, R3.2
VBAT: U$1.P$1, U$1.P$4, VBAT.2
VCC: R2.1, R3.1, U$1.P$2, U$1.P$5



Board: 2 copper layers, 25.5 x 23.1 mm, 6 parts (4 on the bottom side), 5 nets.

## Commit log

2021-01-02 Design Files
    [Design_checks.csv, Texas.brd, Texas.sch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]
2021-11-27 adds alien devil pictures
    [alien_bom.csv]
2021-12-10 adds updates and pics
    [Texas.brd, Texas.sch, Texas.step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]

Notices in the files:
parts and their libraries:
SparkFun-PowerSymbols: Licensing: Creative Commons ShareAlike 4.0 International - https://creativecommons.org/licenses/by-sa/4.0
